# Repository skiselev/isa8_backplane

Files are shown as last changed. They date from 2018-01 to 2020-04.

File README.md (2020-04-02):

# ISA 8-bit Backplane
Compact ISA 8-bit Backplane board

## Introduction
This backplane was designed as a smaller version of [Micro ATX ISA Backplane](https://www.retrobrewcomputers.org/doku.php?id=boards:isa:isa-backplane:start). It can be used to build a compact IBM PC/XT compatible system using the [Micro 8088](https://github.com/skiselev/micro_8088)
processor board, and the 8-bit ISA cards that I've designed:
[ISA Super VGA](http://www.malinov.com/Home/sergeys-projects/isa-supervga),
[ISA Floppy Disk and Serial Controller](http://www.malinov.com/Home/sergeys-projects/isa-fdc-and-uart),
[XT-CF-Lite](http://www.malinov.com/Home/sergeys-projects/xt-cf-lite),
[ISA OPL2](http://www.malinov.com/Home/sergeys-projects/isa-opl2-card).

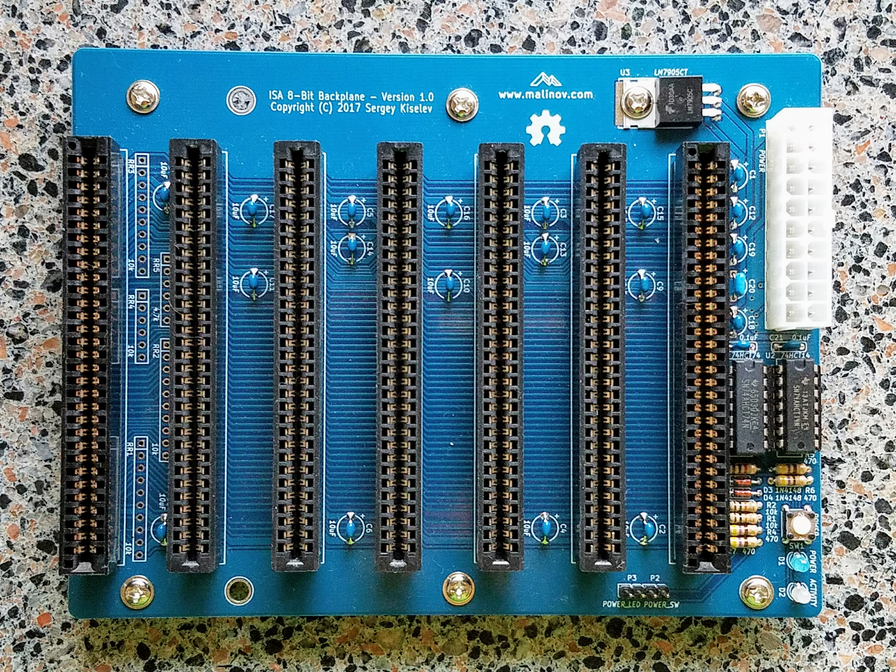
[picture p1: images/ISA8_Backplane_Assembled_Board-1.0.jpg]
ISA 8-bit Backplane V1.0 Assembled Board


## Specifications
* 7 ISA 8-bit (62 pin) slots
* ATX power supply connector, and ATX power control circuit
* Bi-color activity LED, that changes the color when the processor is executing the code (the color changes every time A7 address line changes its value)
* The form factor is (mostly) compatible with ATX / Micro ATX
* Pads for optional termination resistors

## Hardware Documentation

### Schematic and PCB Layout

[Schematic - Version 1.0](KiCad/ISA8_Backplane-Schematic-1.0.pdf)

[PCB Layout - Version 1.0](KiCad/ISA8_Backplane-Board-1.0.pdf)

### Building Insturctions

Please refer to [Building Instructions](Building_Instructions.md) page for detailed instructions.

### Jumpers, Connectors, and Switches

#### P1 - ATX power connector
Pin | Description                    | Pin | Description
--- | ------------------------------ | --- | ------------------------------
1   | +3.3V power supply (not used)  | 11  | +3.3V power supply (not used)
2   |	+3.3V power supply (not used)  | 12  | -12V power supply
3   |	GND                            | 13  | Ground
4   |	+5V power supply               | 14  | Power supply ON signal
5   |	Ground                         | 15  | Ground
6   |	+5V power supply               | 16  | Ground
7   | Ground                         | 17  | Ground
8   | Power good (not used)          | 18  | -5V power supply (not used)*
9   | +5V standby power supply       | 19  | +5V power supply
10  | +12V power supply              | 20  | +5V power supply

*Note: -5V is not provided by most ATX power supplies. It is generated using an on board voltage regulator instead*

#### P2 - Power Switch connector
Pin | Description
--- | -----------
1   | Ground
2   |	Power ON signal

#### P3 - Power LED connector
Pin | Description
--- | -----------
1   | LED+
2   |	Ground

#### SW1 - Power Switch
Press SW1 to turn power on or off. The SW1 is connected in parallel with P2

### Bill of Materials - Version 1.0

[ISA 8-bit Backplane project on Mouser.com](https://www.mouser.com/ProjectManager/ProjectDetail.aspx?AccessID=9a09040b52) - View and order all components except of the PCB.

[ISA 8-bit Backplane project on OSH Park](https://oshpark.com/shared_projects/Y8dcyt5m) - View and order the PCB.

Component type     | Reference | Description                       | Quantity | Possible sources and notes 
------------------ | --------- | --------------------------------- | -------- | --------------------------
PCB                |           | ISA 8-bit Backplane PCB - Version 1.0  | 1   | Refer to the [RetroBrew Computers Board Inventory](https://retrobrewcomputers.org/doku.php?id=boardinventory#xi_8088_project_sergey_kiselev) page for ordering information, or order from a PCB manufacturer of your choice using provided Gerber or KiCad files
Integrated Circuit | U1        | 74HCT74, DIP-14 package           | 1        | Mouser [595-SN74AHCT74N](https://www.mouser.com/ProductDetail/595-SN74AHCT74N)
Integrated Circuit | U2        | 74HCT14, DIP-14 package           | 1        | Mouser [595-SN74AHCT14N](https://www.mouser.com/ProductDetail/595-SN74AHCT14N)
Integrated Circuit | U3        | LM7905C -5V voltage regulator     | 1        | Mouser [512-LM7905CT](https://www.mouser.com/ProductDetail/512-LM7905CT)
IC Socket          | U1, U2    | DIP-14, 300 mil socket            | 2        | Mouser [517-4814-3000-CP](https://www.mouser.com/ProductDetail/517-4814-3000-CP)
LED                | D1        | 3 mm, blue LED indicator          | 1        | Mouser [696-SSL-LX3054USBD](https://www.mouser.com/ProductDetail/696-SSL-LX3054USBD)
LED                | D2        | 3 mm, bi-color red/green LED indicator | 1   | Mouser [696-SSL-LX3054IGW](https://www.mouser.com/ProductDetail/696-SSL-LX3054IGW)
Diode              | D3, D4    | 1N4148                            | 2        | Mouser [512-1N4148](https://www.mouser.com/ProductDetail/512-1N4148)
Tactile Button     | SW1       | 6 mm tactile button, straight     | 1        | Mouser [653-B3F-1000](https://www.mouser.com/ProductDetail/653-B3F-1000)
Connector          | P1        | 20 pin ATX power connector        | 1        | Mouser [538-46015-2006](https://www.mouser.com/ProductDetail/538-46015-2006)
Connector          | P2, P3    | 4 pin header, 2.54 mm pitch       | 2        | Mouser [649-68002-104HLF](https://www.mouser.com/ProductDetail/649-68002-104HLF)
Connector          | BUS1-BUS7 | 62 pin card edge connector, 2.54 mm pitch | 7 | Mouser [571-6-5530843-5](https://www.mouser.com/ProductDetail/571-6-5530843-5)
Capacitor          | C1 - C19  | 10 uF, 16V, MLCC, 5 mm lead spacing    | 19       | Mouser [810-FG28X5R1E106MR06](https://www.mouser.com/ProductDetail/810-FG28X5R1E106MR06)
Capacitor          | C20       | 1 uF, MLCC, 5 mm lead spacing     | 1        | Mouser [810-FG28X5R1H105KRT0](https://www.mouser.com/ProductDetail/810-FG28X5R1H105KRT0)
Capacitor          | C21, C22  | 0.1 uF, MLCC, 5 mm lead spacing   | 2        | Mouser [594-K104K15X7RF53H5](https://www.mouser.com/ProductDetail/594-K104K15X7RF53H5)
Resistor           | R1, R2    | 10 kohm, through hole             | 2        | Mouser [291-10K-RC](https://www.mouser.com/ProductDetail/291-10K-RC)
Resistor           | R3        | 1 kohm, through hole              | 1        | Mouser [291-1K-RC](https://www.mouser.com/ProductDetail/291-1K-RC)
Resistor           | R4 - R7   | 470 ohm, through hole             | 4        | Mouser [291-470-RC](https://www.mouser.com/ProductDetail/291-470-RC)
Resistor Array     | RR1 - RR5 | do not populate                   |          | Optional, should not be populated

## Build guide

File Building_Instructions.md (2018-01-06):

# ISA 8-bit Backplane - Building Instructions

## Prerequisites

### Tools, Equipment, and Supplies

* Soldering iron with a fine tip. Temperature controlled soldering station is recommended
* Needle nose pliers for forming components' leads
* Small side cutters for cutting components' leads
* Desk lamp, magnifying glass
* Solder suitable for soldering electronics. For example: rosin core Sn63/Pb37, Sn60/Pb40, or a lead-free solder such as Sn96.5/Ag3.0/Cu0.5 (sometimes referred to as SAC305)
* Solder wick for removing excess of solder
* 99% Isopropyl Alcohol for removing the excess of flux after soldering
* Lint free wipes, used toothbrush, cotton swabs for cleaning the PCB before and after soldering

### Parts

#### Procuring Parts
The list of parts provided in the [Bill of Materials](README.md#bill-of-materials---version-10) section of the [README.md](README.md) file. It also provides the recommended sources for the parts.
Most of the parts are available from electronic components distributors such as [Mouser](https://www.mouser.com/ProjectManager/ProjectDetail.aspx?AccessID=9a09040b52) and [Digi-Key](https://www.digikey.com).
Many components are also available, frequently cheaper, from smaller stores, such as [Unicorn Electronics](http://www.unicornelectronics.com/), or on eBay.

The ISA 8-bit Backplane PCBs are provided by the members of [RetroBrew Computers group](https://retrobrewcomputers.org/doku.php?id=boardinventory#xi_8088_project_sergey_kiselev).
Alternatively they can be ordered from a PCB manufacturing service, such as [OSH Park](https://oshpark.com/shared_projects/Y8dcyt5m),
using [Gerber](gerber) or [KiCad](KiCad) files provided in this GitHub repository.

It is highly recommended to use high quality gold plated card edge connectors (ISA 62-pin connectors). Using lower quality, especially old stock, corroded connectors will result in unreliable system.

#### Parts Replacement

* The recommended logic family is the CMOS 74HCT-series
  * Possible replacements are Advanced CMOS 74AHCT, or CMOS 74ACT-series logic
  * While TTL ICs (74LS, 74ALS, 74F) should work, they will result in higher power consumption
* LEDs:
  * Power LED - D1: It is recommended to use a 3 mm blue LED. 5 mm LEDs, as well as other colors would work as well.
  * Activity LED - D2: It is recommended to use a 3 mm red/green bi-color LED. This LED must be a bi-color LED with two leads. Such LEDs integrate two LED crystals, connected back to back (anode of one to cathod of the other, and vice-versa).
* It is recommended to use ceramic multilayer capacitors with 5 mm lead pitch
  * It is possible to use 2.5 mm lead pitch or axial capacitors by forming their leads accordingly
  * Electrolytic or tantalum capacitors can be used for C1-C19 10 uF. Make sure to observe the polarity in this case

## Building the ISA 8-bit Backplane Board

### Build Sequence

1. Inspect the PCB for obvious defects, such as deep scratches or short-circuits between traces
2. Clean the PCB with an alcohol wipe
3. Solder the components, going for lower profile to higher profile
  * Form the leads and solder the D3 and D4 diodes. Pay attention to the diode's polarity (the black band on the diode should match the band on the silkscreen)
  * Solder the R1-R7 resistors
  * Solder the SW1 tactile button
  * Form the leads and solder the U3 power regulator. Make sure that the heatsink mount hole is right above the mount hole in the PCB
  * Solder the C1-C22 capacitors. Pay attention to the capacitors polarity if using polarized capacitors
  * Solder the DIP sockets - U1, U2. Pay close attention to the orientation of the sockets
  * Solder the LEDs D1 and D2. Pay attention to the LED polarity for D1
  * Solder the P2 - P3 header
  * Solder the P1 ATX power connector
  * Solder the BUS1 - BUS7 ISA card edge connectors
4. Carefully inspect all the solder joints. Re-solder if needed. Optionally use a multimeter to check the board for short-circuits, and for the power supply signals connectivity
5. Clean the board using cotton swaps, wipes, and the toothbrush soaked in alcohol
6. Carefully install ICs into the sockets. Use a hard non-static surface to bend the pins of ICs in DIP packages as needed. Double check the orientation of the ICs. Make sure that all ICs pins are inserted into the sockets, and not bent
7. Inspect the completed board once again
8. Install the Micro 8088 board and other ISA cards in the ISA backplane. Connect the power supply
9. Turn on the power, test the board, install your favorite software, and enjoy!

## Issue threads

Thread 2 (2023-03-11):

24pin ATX

lis-86, 2023-03-11:
Possible rewiring to 24 pin ATX power?

prabathbr, 2023-06-07:
> Possible rewiring to 24 pin ATX power?

you can simple remove additional 4 pins or use 24 pin -> 20 pin extension cable for couple of $ to keep it clean.

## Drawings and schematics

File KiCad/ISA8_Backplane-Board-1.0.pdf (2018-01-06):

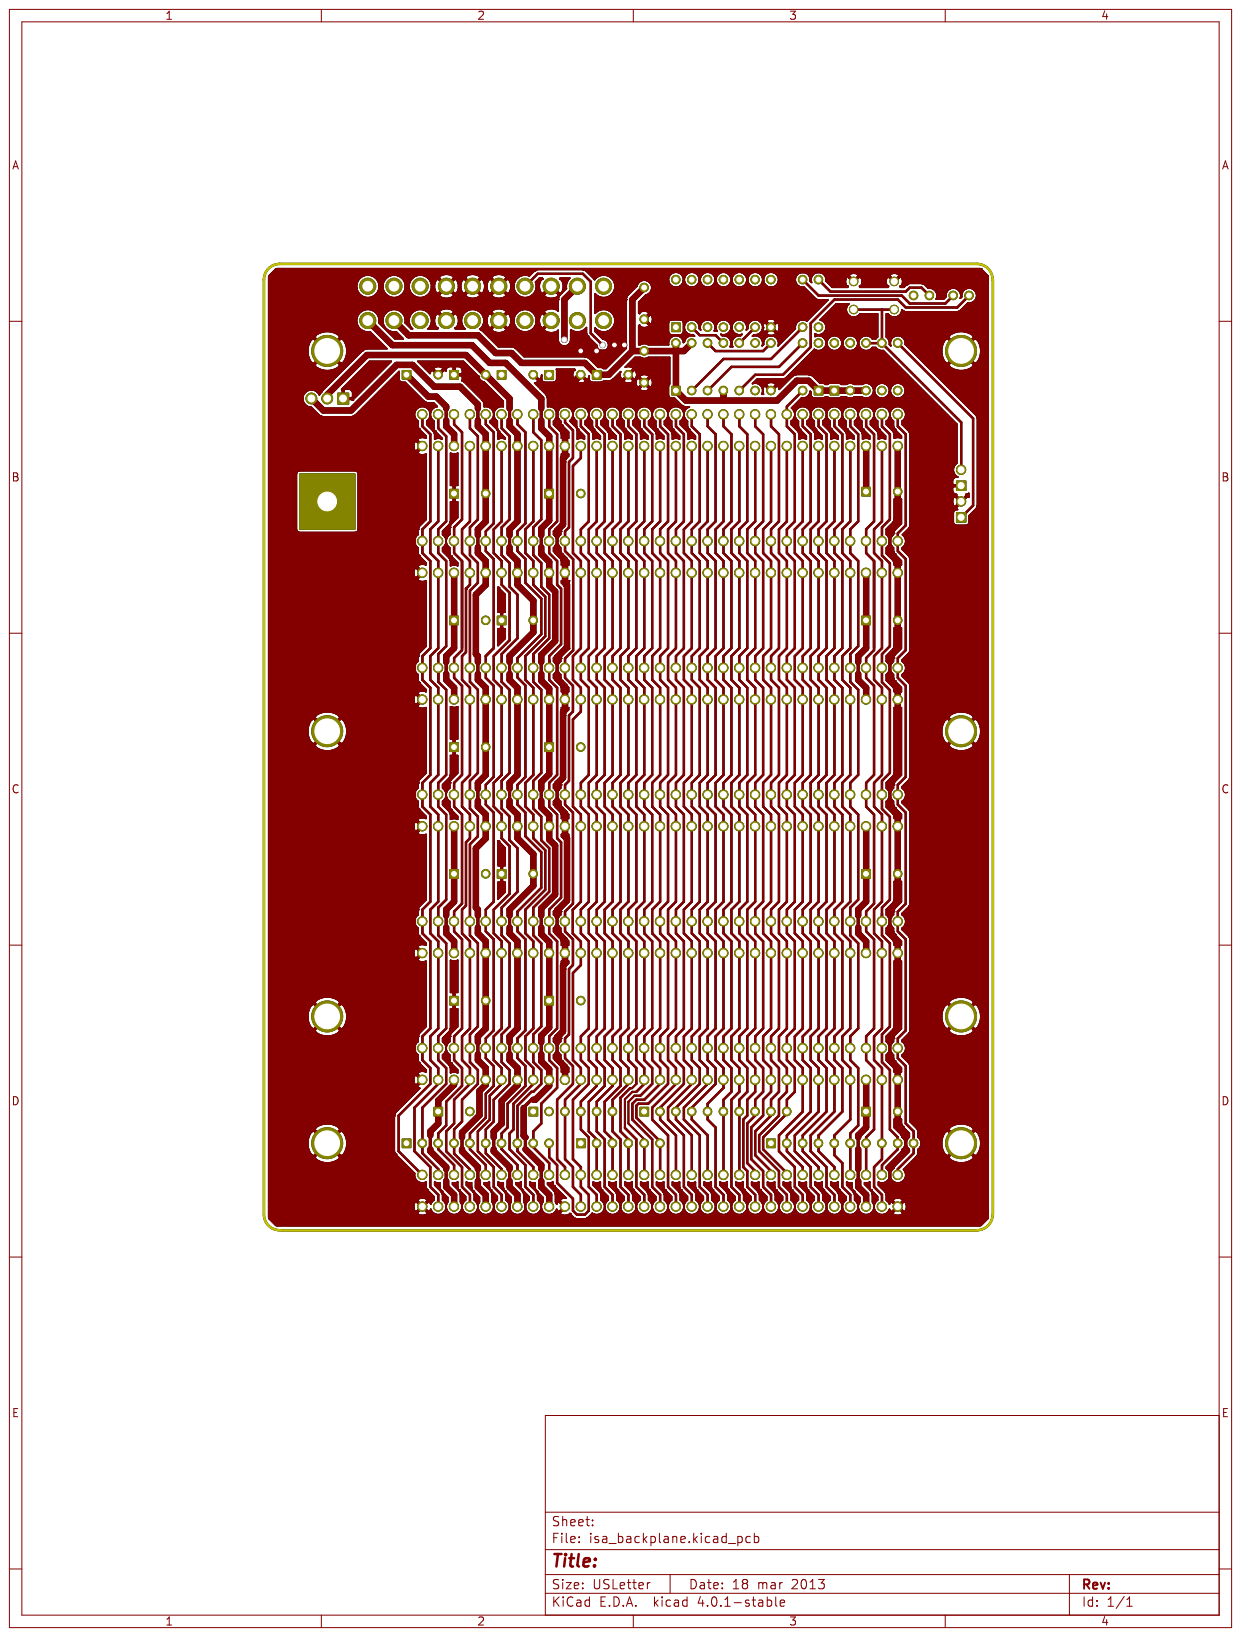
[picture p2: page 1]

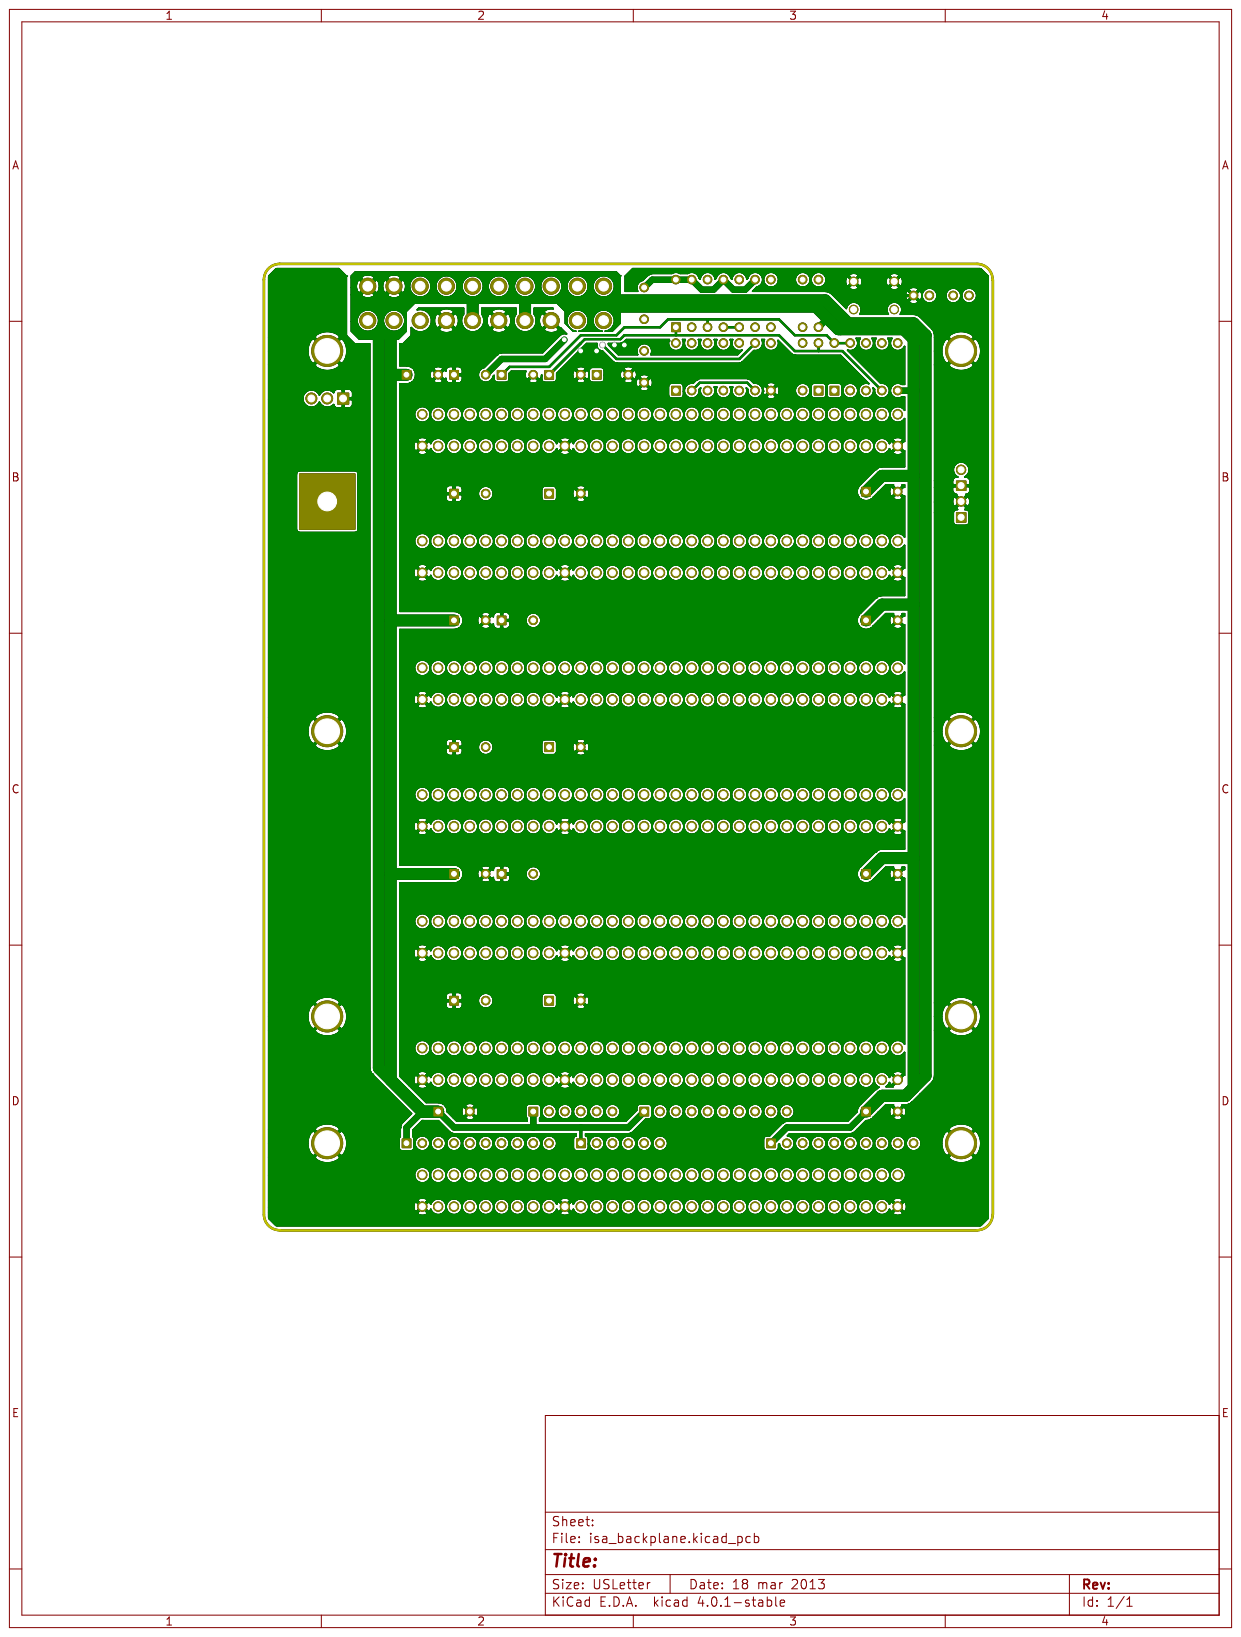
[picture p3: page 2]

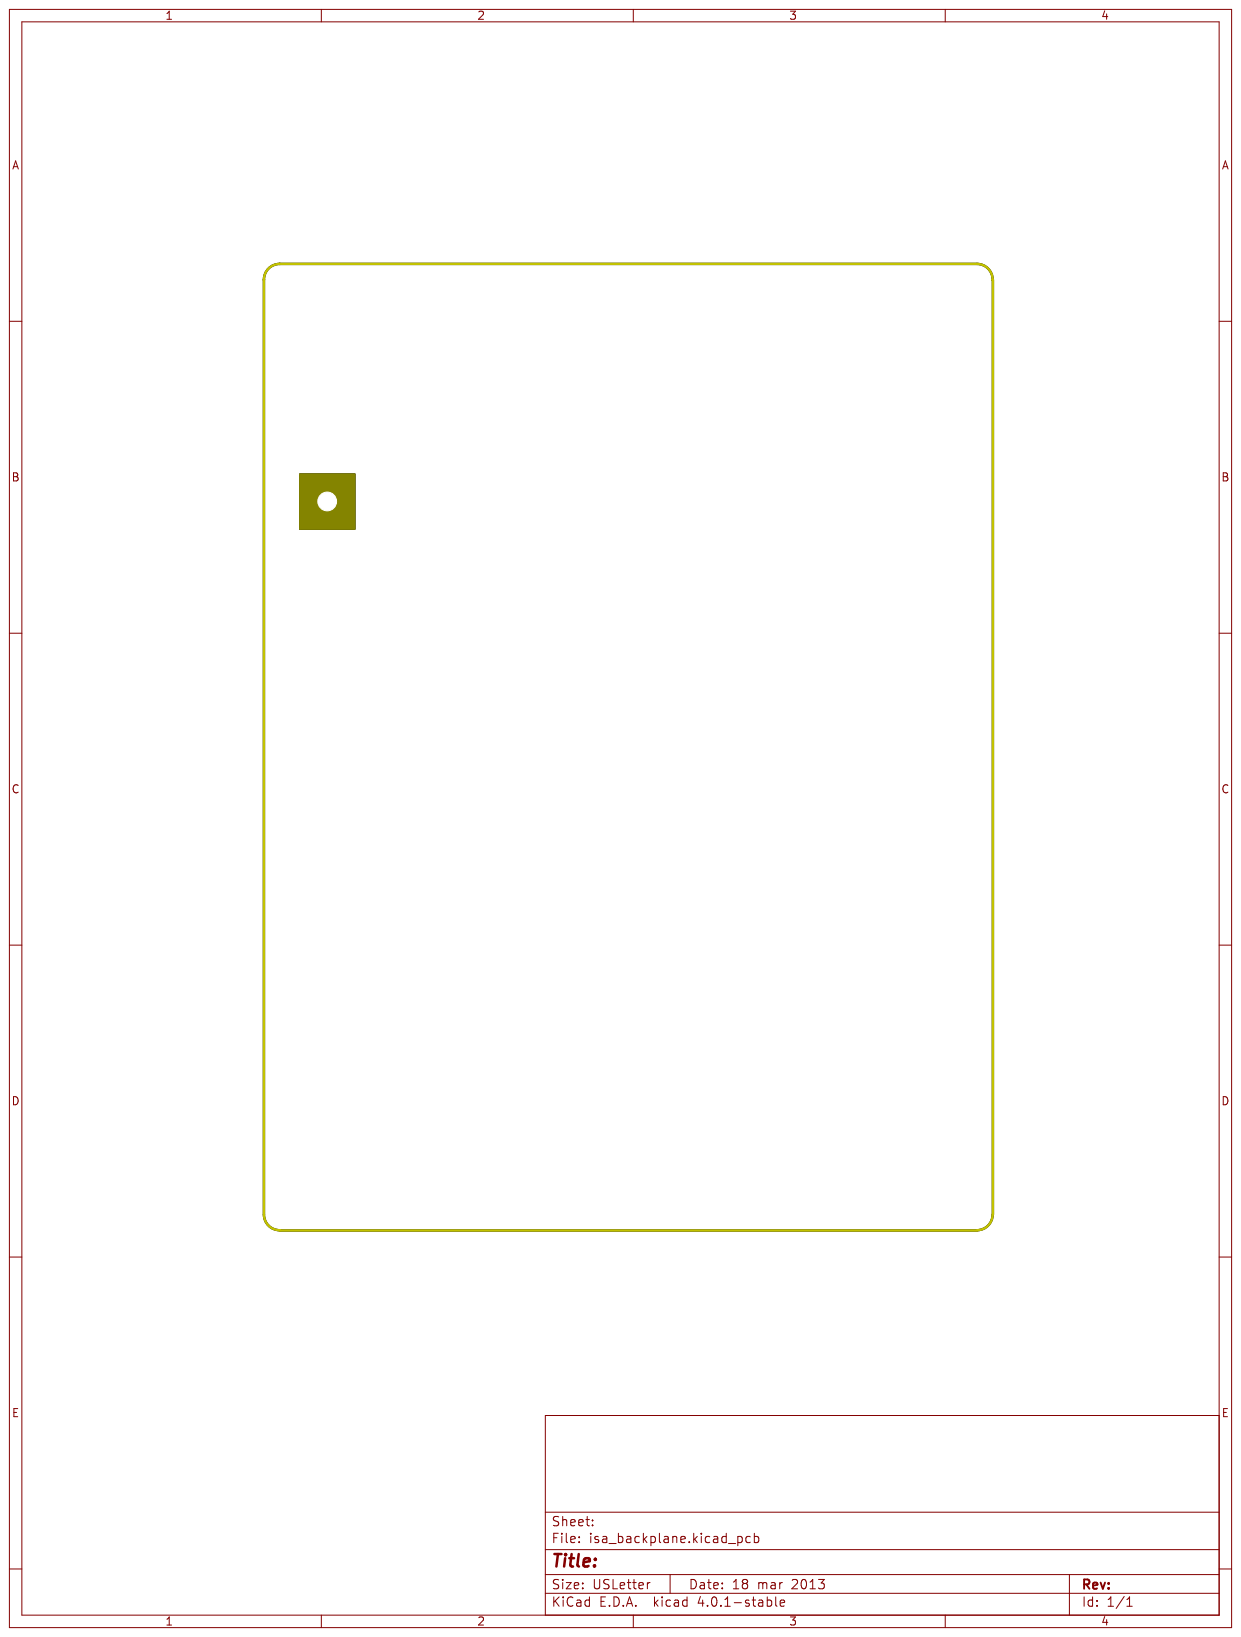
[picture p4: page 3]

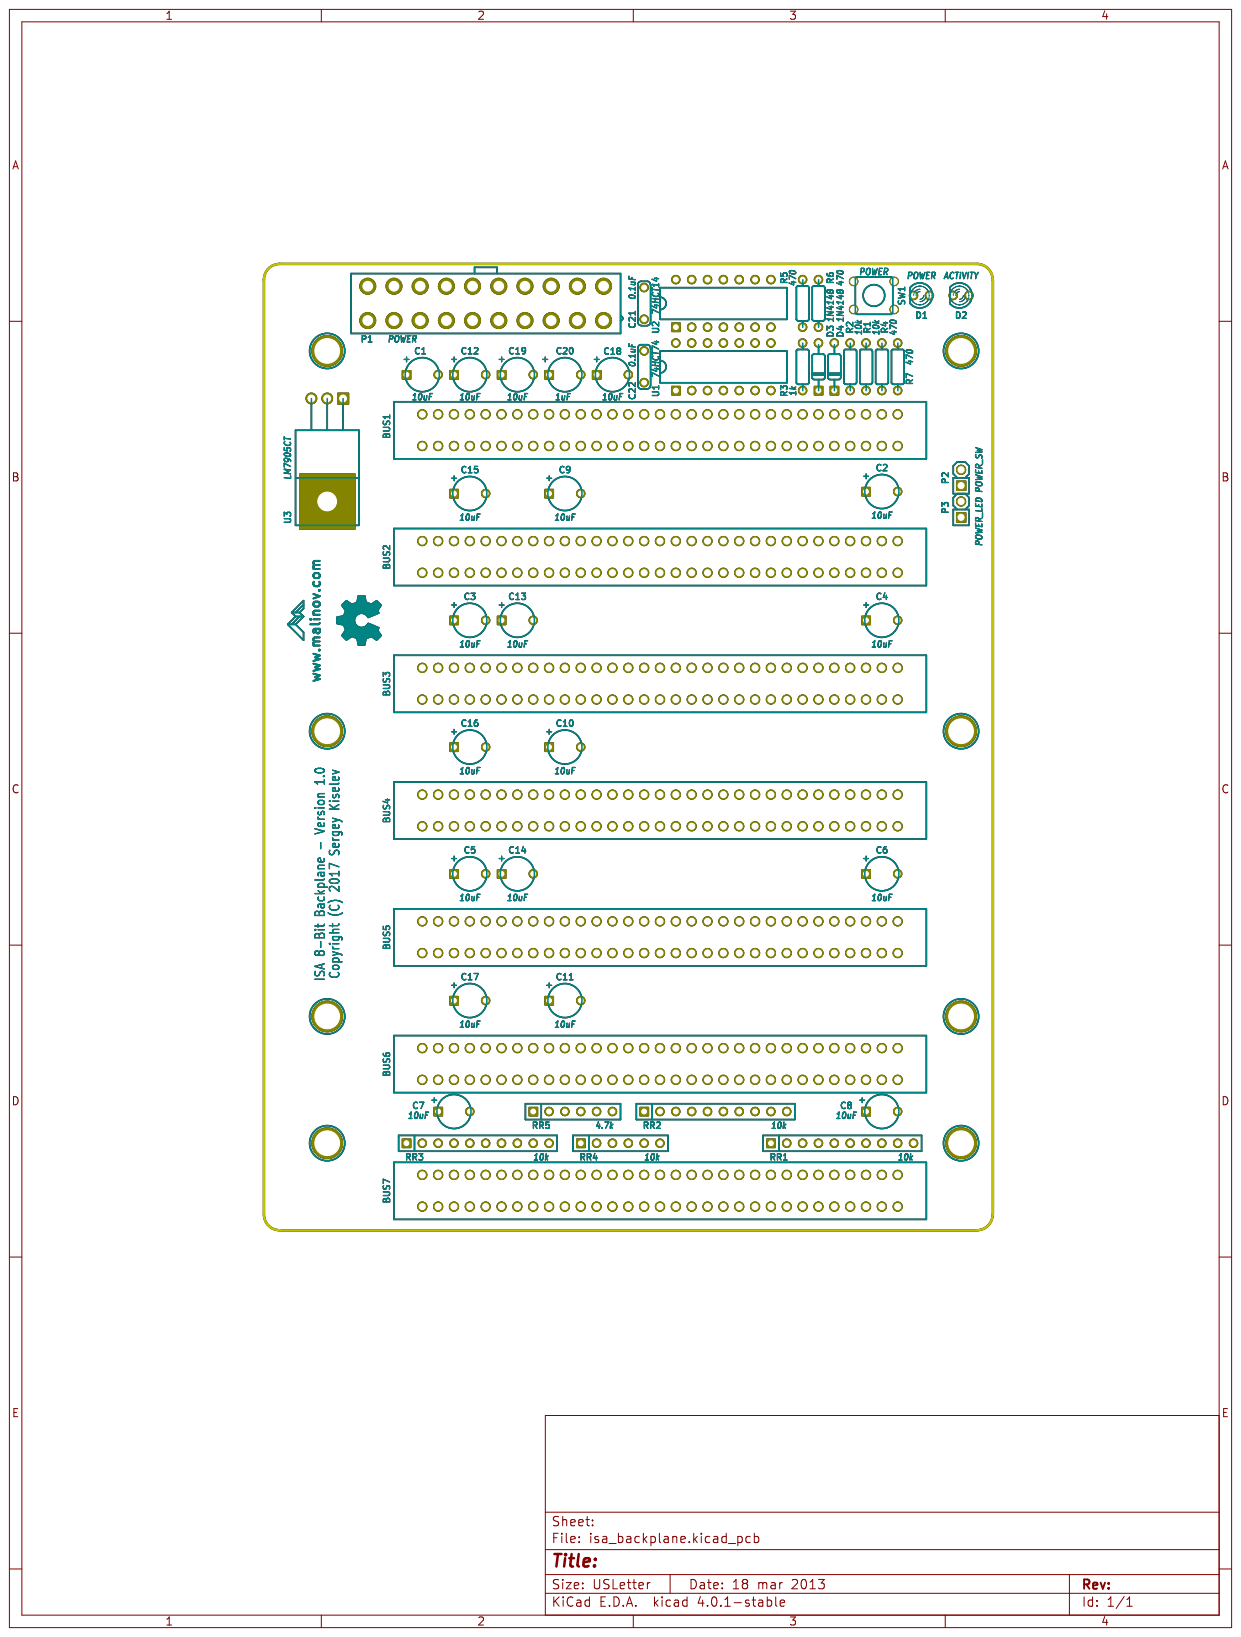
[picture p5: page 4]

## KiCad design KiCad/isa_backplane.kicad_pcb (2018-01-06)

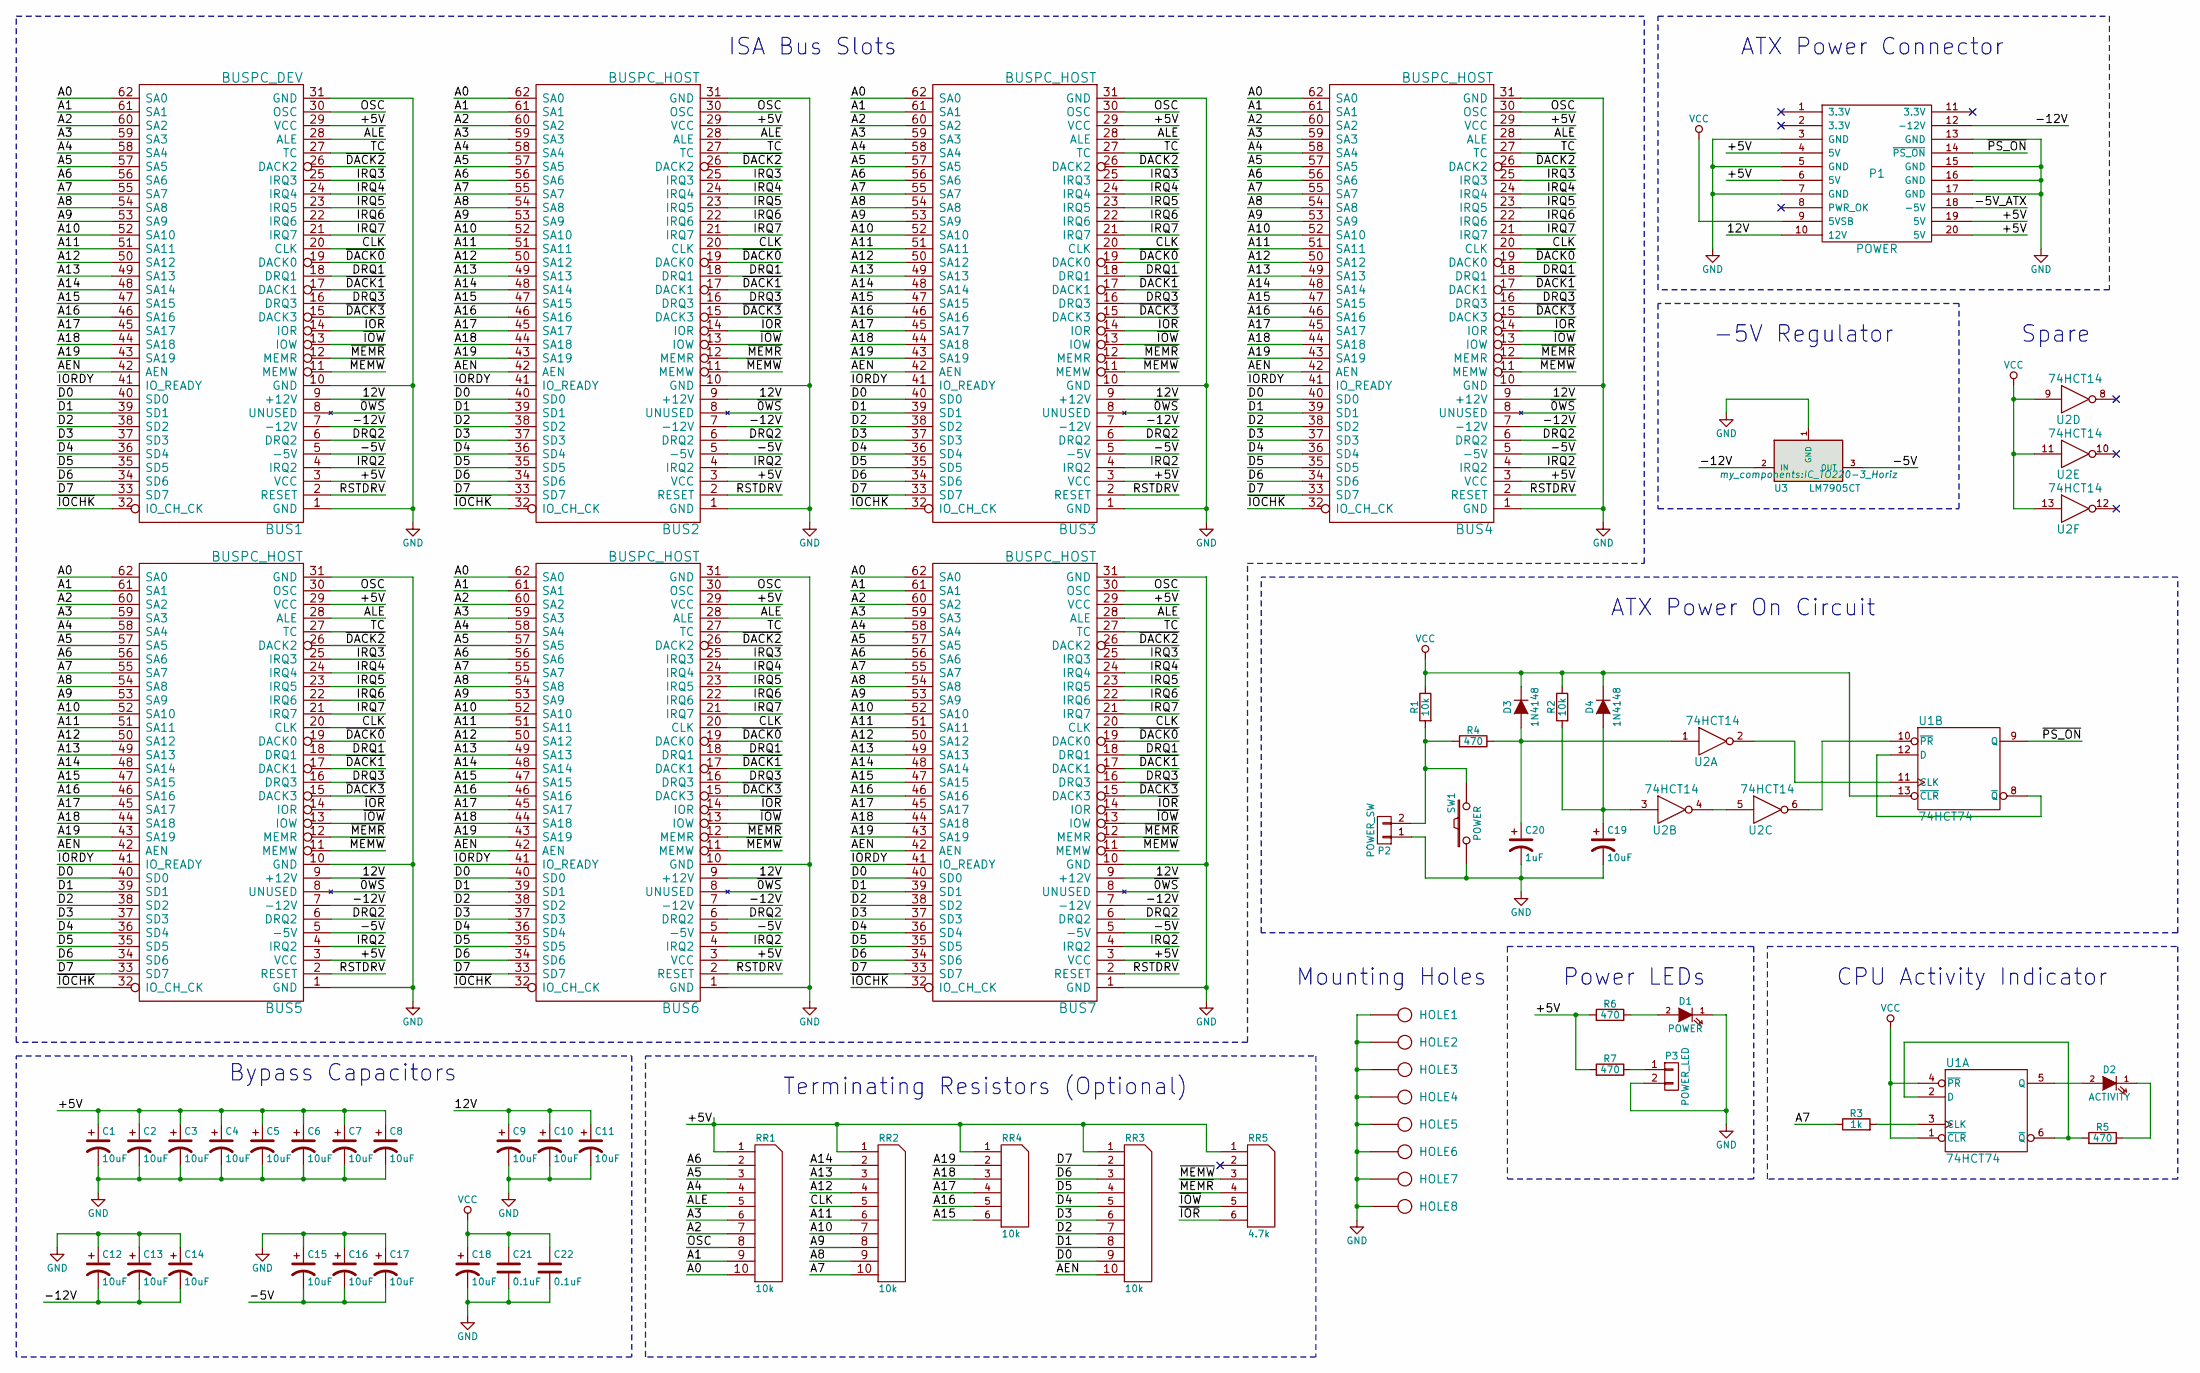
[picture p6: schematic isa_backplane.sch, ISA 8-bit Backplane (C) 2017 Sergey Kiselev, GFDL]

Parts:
BUS1: BUSPC_DEV; Conn_Edge_ISA8
BUS2, BUS3, BUS4, BUS5, BUS6, BUS7: BUSPC_HOST; Conn_Edge_ISA8
C1, C2, C3, C4, C5, C6, C7, C8, C9, C10, C11, C12, C13, C14, C15, C16, C17, C18, C19: 10uF; Cap_Tant_508
C20: 1uF; Cap_Tant_508
C21, C22: 0.1uF; Cap_Cer_508
D1: POWER; LED_3mm
D2: ACTIVITY; LED_3mm
D3, D4: 1N4148; Diode_762
HOLE1, HOLE2, HOLE3, HOLE4, HOLE5, HOLE6, HOLE7, HOLE8: HOLE; Hole_4mm
P1: POWER; Conn_Power_ATX_20pin
P2: POWER_SW; Conn_Pin_Header_2x1_2.54mm
P3: POWER_LED; Conn_Pin_Header_2x1_2.54mm
R1, R2: 10k; Res_762
R3: 1k; Res_762
R4, R5, R6, R7: 470; Res_762
RR1, RR2, RR3: 10k; Conn_SIL10
RR4: 10k; Conn_SIL6
RR5: 4.7k; Conn_SIL6
SW1: POWER; Switch_Tactile_6mm
U1: 74HCT74; IC_DIP14_300
U2: 74HCT14; IC_DIP14_300
U3: LM7905CT; IC_TO220-3_Horiz

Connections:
/12V: BUS1.9 (+12V), BUS2.9 (+12V), BUS3.9 (+12V), BUS4.9 (+12V), BUS5.9 (+12V), BUS6.9 (+12V), BUS7.9 (+12V), C9.1, C10.1, C11.1, P1.10 (12V)
/+5V: BUS1.3 (VCC), BUS1.29 (VCC), BUS2.3 (VCC), BUS2.29 (VCC), BUS3.3 (VCC), BUS3.29 (VCC), BUS4.3 (VCC), BUS4.29 (VCC), BUS5.3 (VCC), BUS5.29 (VCC), BUS6.3 (VCC), BUS6.29 (VCC), BUS7.3 (VCC), BUS7.29 (VCC), C1.1, C2.1, C3.1, C4.1, C5.1, C6.1, C7.1, C8.1, P1.4 (5V), P1.6 (5V), P1.19 (5V), P1.20 (5V), R6.2, R7.2, RR1.1 (COM), RR2.1 (COM), RR3.1 (COM), RR4.1 (COM), RR5.1 (COM)
/-5V: BUS1.5 (-5V), BUS2.5 (-5V), BUS3.5 (-5V), BUS4.5 (-5V), BUS5.5 (-5V), BUS6.5 (-5V), BUS7.5 (-5V), C15.2, C16.2, C17.2, U3.3 (OUT)
/-5V_ATX: P1.18 (-5V)
/-12V: BUS1.7 (-12V), BUS2.7 (-12V), BUS3.7 (-12V), BUS4.7 (-12V), BUS5.7 (-12V), BUS6.7 (-12V), BUS7.7 (-12V), C12.2, C13.2, C14.2, P1.12 (-12V), U3.2 (IN)
/A0: BUS1.62 (SA0), BUS2.62 (SA0), BUS3.62 (SA0), BUS4.62 (SA0), BUS5.62 (SA0), BUS6.62 (SA0), BUS7.62 (SA0), RR1.10
/A1: BUS1.61 (SA1), BUS2.61 (SA1), BUS3.61 (SA1), BUS4.61 (SA1), BUS5.61 (SA1), BUS6.61 (SA1), BUS7.61 (SA1), RR1.9
/A2: BUS1.60 (SA2), BUS2.60 (SA2), BUS3.60 (SA2), BUS4.60 (SA2), BUS5.60 (SA2), BUS6.60 (SA2), BUS7.60 (SA2), RR1.7
/A3: BUS1.59 (SA3), BUS2.59 (SA3), BUS3.59 (SA3), BUS4.59 (SA3), BUS5.59 (SA3), BUS6.59 (SA3), BUS7.59 (SA3), RR1.6
/A4: BUS1.58 (SA4), BUS2.58 (SA4), BUS3.58 (SA4), BUS4.58 (SA4), BUS5.58 (SA4), BUS6.58 (SA4), BUS7.58 (SA4), RR1.4
/A5: BUS1.57 (SA5), BUS2.57 (SA5), BUS3.57 (SA5), BUS4.57 (SA5), BUS5.57 (SA5), BUS6.57 (SA5), BUS7.57 (SA5), RR1.3
/A6: BUS1.56 (SA6), BUS2.56 (SA6), BUS3.56 (SA6), BUS4.56 (SA6), BUS5.56 (SA6), BUS6.56 (SA6), BUS7.56 (SA6), RR1.2
/A7: BUS1.55 (SA7), BUS2.55 (SA7), BUS3.55 (SA7), BUS4.55 (SA7), BUS5.55 (SA7), BUS6.55 (SA7), BUS7.55 (SA7), R3.1, RR2.10
/A8: BUS1.54 (SA8), BUS2.54 (SA8), BUS3.54 (SA8), BUS4.54 (SA8), BUS5.54 (SA8), BUS6.54 (SA8), BUS7.54 (SA8), RR2.9
/A9: BUS1.53 (SA9), BUS2.53 (SA9), BUS3.53 (SA9), BUS4.53 (SA9), BUS5.53 (SA9), BUS6.53 (SA9), BUS7.53 (SA9), RR2.8
/A10: BUS1.52 (SA10), BUS2.52 (SA10), BUS3.52 (SA10), BUS4.52 (SA10), BUS5.52 (SA10), BUS6.52 (SA10), BUS7.52 (SA10), RR2.7
/A11: BUS1.51 (SA11), BUS2.51 (SA11), BUS3.51 (SA11), BUS4.51 (SA11), BUS5.51 (SA11), BUS6.51 (SA11), BUS7.51 (SA11), RR2.6
/A12: BUS1.50 (SA12), BUS2.50 (SA12), BUS3.50 (SA12), BUS4.50 (SA12), BUS5.50 (SA12), BUS6.50 (SA12), BUS7.50 (SA12), RR2.4
/A13: BUS1.49 (SA13), BUS2.49 (SA13), BUS3.49 (SA13), BUS4.49 (SA13), BUS5.49 (SA13), BUS6.49 (SA13), BUS7.49 (SA13), RR2.3
/A14: BUS1.48 (SA14), BUS2.48 (SA14), BUS3.48 (SA14), BUS4.48 (SA14), BUS5.48 (SA14), BUS6.48 (SA14), BUS7.48 (SA14), RR2.2
/A15: BUS1.47 (SA15), BUS2.47 (SA15), BUS3.47 (SA15), BUS4.47 (SA15), BUS5.47 (SA15), BUS6.47 (SA15), BUS7.47 (SA15), RR4.6
/A16: BUS1.46 (SA16), BUS2.46 (SA16), BUS3.46 (SA16), BUS4.46 (SA16), BUS5.46 (SA16), BUS6.46 (SA16), BUS7.46 (SA16), RR4.5
/A17: BUS1.45 (SA17), BUS2.45 (SA17), BUS3.45 (SA17), BUS4.45 (SA17), BUS5.45 (SA17), BUS6.45 (SA17), BUS7.45 (SA17), RR4.4
/A18: BUS1.44 (SA18), BUS2.44 (SA18), BUS3.44 (SA18), BUS4.44 (SA18), BUS5.44 (SA18), BUS6.44 (SA18), BUS7.44 (SA18), RR4.3
/A19: BUS1.43 (SA19), BUS2.43 (SA19), BUS3.43 (SA19), BUS4.43 (SA19), BUS5.43 (SA19), BUS6.43 (SA19), BUS7.43 (SA19), RR4.2
/AEN: BUS1.42 (AEN), BUS2.42 (AEN), BUS3.42 (AEN), BUS4.42 (AEN), BUS5.42 (AEN), BUS6.42 (AEN), BUS7.42 (AEN), RR3.10
/ALE: BUS1.28 (ALE), BUS2.28 (ALE), BUS3.28 (ALE), BUS4.28 (ALE), BUS5.28 (ALE), BUS6.28 (ALE), BUS7.28 (ALE), RR1.5
/CLK: BUS1.20 (CLK), BUS2.20 (CLK), BUS3.20 (CLK), BUS4.20 (CLK), BUS5.20 (CLK), BUS6.20 (CLK), BUS7.20 (CLK), RR2.5
/D0: BUS1.40 (SD0), BUS2.40 (SD0), BUS3.40 (SD0), BUS4.40 (SD0), BUS5.40 (SD0), BUS6.40 (SD0), BUS7.40 (SD0), RR3.9
/D1: BUS1.39 (SD1), BUS2.39 (SD1), BUS3.39 (SD1), BUS4.39 (SD1), BUS5.39 (SD1), BUS6.39 (SD1), BUS7.39 (SD1), RR3.8
/D2: BUS1.38 (SD2), BUS2.38 (SD2), BUS3.38 (SD2), BUS4.38 (SD2), BUS5.38 (SD2), BUS6.38 (SD2), BUS7.38 (SD2), RR3.7
/D3: BUS1.37 (SD3), BUS2.37 (SD3), BUS3.37 (SD3), BUS4.37 (SD3), BUS5.37 (SD3), BUS6.37 (SD3), BUS7.37 (SD3), RR3.6
/D4: BUS1.36 (SD4), BUS2.36 (SD4), BUS3.36 (SD4), BUS4.36 (SD4), BUS5.36 (SD4), BUS6.36 (SD4), BUS7.36 (SD4), RR3.5
/D5: BUS1.35 (SD5), BUS2.35 (SD5), BUS3.35 (SD5), BUS4.35 (SD5), BUS5.35 (SD5), BUS6.35 (SD5), BUS7.35 (SD5), RR3.4
/D6: BUS1.34 (SD6), BUS2.34 (SD6), BUS3.34 (SD6), BUS4.34 (SD6), BUS5.34 (SD6), BUS6.34 (SD6), BUS7.34 (SD6), RR3.3
/D7: BUS1.33 (SD7), BUS2.33 (SD7), BUS3.33 (SD7), BUS4.33 (SD7), BUS5.33 (SD7), BUS6.33 (SD7), BUS7.33 (SD7), RR3.2
/DRQ1: BUS1.18 (DRQ1), BUS2.18 (DRQ1), BUS3.18 (DRQ1), BUS4.18 (DRQ1), BUS5.18 (DRQ1), BUS6.18 (DRQ1), BUS7.18 (DRQ1)
/DRQ2: BUS1.6 (DRQ2), BUS2.6 (DRQ2), BUS3.6 (DRQ2), BUS4.6 (DRQ2), BUS5.6 (DRQ2), BUS6.6 (DRQ2), BUS7.6 (DRQ2)
/DRQ3: BUS1.16 (DRQ3), BUS2.16 (DRQ3), BUS3.16 (DRQ3), BUS4.16 (DRQ3), BUS5.16 (DRQ3), BUS6.16 (DRQ3), BUS7.16 (DRQ3)
/IORDY: BUS1.41 (IO_READY), BUS2.41 (IO_READY), BUS3.41 (IO_READY), BUS4.41 (IO_READY), BUS5.41 (IO_READY), BUS6.41 (IO_READY), BUS7.41 (IO_READY)
/IRQ2: BUS1.4 (IRQ2), BUS2.4 (IRQ2), BUS3.4 (IRQ2), BUS4.4 (IRQ2), BUS5.4 (IRQ2), BUS6.4 (IRQ2), BUS7.4 (IRQ2)
/IRQ3: BUS1.25 (IRQ3), BUS2.25 (IRQ3), BUS3.25 (IRQ3), BUS4.25 (IRQ3), BUS5.25 (IRQ3), BUS6.25 (IRQ3), BUS7.25 (IRQ3)
/IRQ4: BUS1.24 (IRQ4), BUS2.24 (IRQ4), BUS3.24 (IRQ4), BUS4.24 (IRQ4), BUS5.24 (IRQ4), BUS6.24 (IRQ4), BUS7.24 (IRQ4)
/IRQ5: BUS1.23 (IRQ5), BUS2.23 (IRQ5), BUS3.23 (IRQ5), BUS4.23 (IRQ5), BUS5.23 (IRQ5), BUS6.23 (IRQ5), BUS7.23 (IRQ5)
/IRQ6: BUS1.22 (IRQ6), BUS2.22 (IRQ6), BUS3.22 (IRQ6), BUS4.22 (IRQ6), BUS5.22 (IRQ6), BUS6.22 (IRQ6), BUS7.22 (IRQ6)
/IRQ7: BUS1.21 (IRQ7), BUS2.21 (IRQ7), BUS3.21 (IRQ7), BUS4.21 (IRQ7), BUS5.21 (IRQ7), BUS6.21 (IRQ7), BUS7.21 (IRQ7)
/OSC: BUS1.30 (OSC), BUS2.30 (OSC), BUS3.30 (OSC), BUS4.30 (OSC), BUS5.30 (OSC), BUS6.30 (OSC), BUS7.30 (OSC), RR1.8
/RSTDRV: BUS1.2 (RESET), BUS2.2 (RESET), BUS3.2 (RESET), BUS4.2 (RESET), BUS5.2 (RESET), BUS6.2 (RESET), BUS7.2 (RESET)
/TC: BUS1.27 (TC), BUS2.27 (TC), BUS3.27 (TC), BUS4.27 (TC), BUS5.27 (TC), BUS6.27 (TC), BUS7.27 (TC)
/~0WS: BUS1.8 (UNUSED), BUS2.8 (UNUSED), BUS3.8 (UNUSED), BUS4.8 (UNUSED), BUS5.8 (UNUSED), BUS6.8 (UNUSED), BUS7.8 (UNUSED)
/~DACK0: BUS1.19 (DACK0), BUS2.19 (DACK0), BUS3.19 (DACK0), BUS4.19 (DACK0), BUS5.19 (DACK0), BUS6.19 (DACK0), BUS7.19 (DACK0)
/~DACK1: BUS1.17 (DACK1), BUS2.17 (DACK1), BUS3.17 (DACK1), BUS4.17 (DACK1), BUS5.17 (DACK1), BUS6.17 (DACK1), BUS7.17 (DACK1)
/~DACK2: BUS1.26 (DACK2), BUS2.26 (DACK2), BUS3.26 (DACK2), BUS4.26 (DACK2), BUS5.26 (DACK2), BUS6.26 (DACK2), BUS7.26 (DACK2)
/~DACK3: BUS1.15 (DACK3), BUS2.15 (DACK3), BUS3.15 (DACK3), BUS4.15 (DACK3), BUS5.15 (DACK3), BUS6.15 (DACK3), BUS7.15 (DACK3)
/~IOCHK: BUS1.32 (IO_CH_CK), BUS2.32 (IO_CH_CK), BUS3.32 (IO_CH_CK), BUS4.32 (IO_CH_CK), BUS5.32 (IO_CH_CK), BUS6.32 (IO_CH_CK), BUS7.32 (IO_CH_CK)
/~IOR: BUS1.14 (IOR), BUS2.14 (IOR), BUS3.14 (IOR), BUS4.14 (IOR), BUS5.14 (IOR), BUS6.14 (IOR), BUS7.14 (IOR), RR5.6
/~IOW: BUS1.13 (IOW), BUS2.13 (IOW), BUS3.13 (IOW), BUS4.13 (IOW), BUS5.13 (IOW), BUS6.13 (IOW), BUS7.13 (IOW), RR5.5
/~MEMR: BUS1.12 (MEMR), BUS2.12 (MEMR), BUS3.12 (MEMR), BUS4.12 (MEMR), BUS5.12 (MEMR), BUS6.12 (MEMR), BUS7.12 (MEMR), RR5.4
/~MEMW: BUS1.11 (MEMW), BUS2.11 (MEMW), BUS3.11 (MEMW), BUS4.11 (MEMW), BUS5.11 (MEMW), BUS6.11 (MEMW), BUS7.11 (MEMW), RR5.3
/~PS_ON: P1.14 (~PS_ON), U1.9 (Q)
GND: BUS1.1 (GND), BUS1.10 (GND), BUS1.31 (GND), BUS2.1 (GND), BUS2.10 (GND), BUS2.31 (GND), BUS3.1 (GND), BUS3.10 (GND), BUS3.31 (GND), BUS4.1 (GND), BUS4.10 (GND), BUS4.31 (GND), BUS5.1 (GND), BUS5.10 (GND), BUS5.31 (GND), BUS6.1 (GND), BUS6.10 (GND), BUS6.31 (GND), BUS7.1 (GND), BUS7.10 (GND), BUS7.31 (GND), C1.2, C2.2, C3.2, C4.2, C5.2, C6.2, C7.2, C8.2, C9.2, C10.2, C11.2, C12.1, C13.1, C14.1, C15.1, C16.1, C17.1, C18.2, C19.2, C20.2, C21.2, C22.2, D1.1 (K), HOLE1.1, HOLE2.1, HOLE3.1, HOLE4.1, HOLE5.1, HOLE6.1, HOLE7.1, HOLE8.1, P1.3 (GND), P1.5 (GND), P1.7 (GND), P1.13 (GND), P1.15 (GND), P1.16 (GND), P1.17 (GND), P2.1, P3.2, SW1.1, U1.7 (GND), U2.7 (GND), U3.1 (GND)
unnamed: C19.1, D4.2 (A), R2.2, U2.3
unnamed: C20.1, D3.2 (A), R4.1, U2.1
unnamed: D1.2 (A), R6.1
unnamed: D2.1 (K), R5.1
unnamed: D2.2 (A), U1.5 (Q)
unnamed: P2.2, R1.2, R4.2, SW1.2
unnamed: P3.1, R7.1
unnamed: R3.2, U1.3 (CLK)
unnamed: R5.2, U1.2 (D), U1.6 (~Q)
unnamed: U1.10 (~PR), U2.6
unnamed: U1.11 (CLK), U2.2
unnamed: U1.8 (~Q), U1.12 (D)
unnamed: U2.4, U2.5
VCC: C18.1, C21.1, C22.1, D3.1 (K), D4.1 (K), P1.9 (5VSB), R1.1, R2.1, U1.1 (~CLR), U1.4 (~PR), U1.13 (~CLR), U1.14 (VCC), U2.9, U2.11, U2.13, U2.14 (VCC)

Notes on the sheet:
Power LEDs
-5V Regulator
CPU Activity Indicator
ATX Power Connector
Mounting Holes
ATX Power On Circuit
Bypass Capacitors
ISA Bus Slots
Terminating Resistors (Optional)
Spare

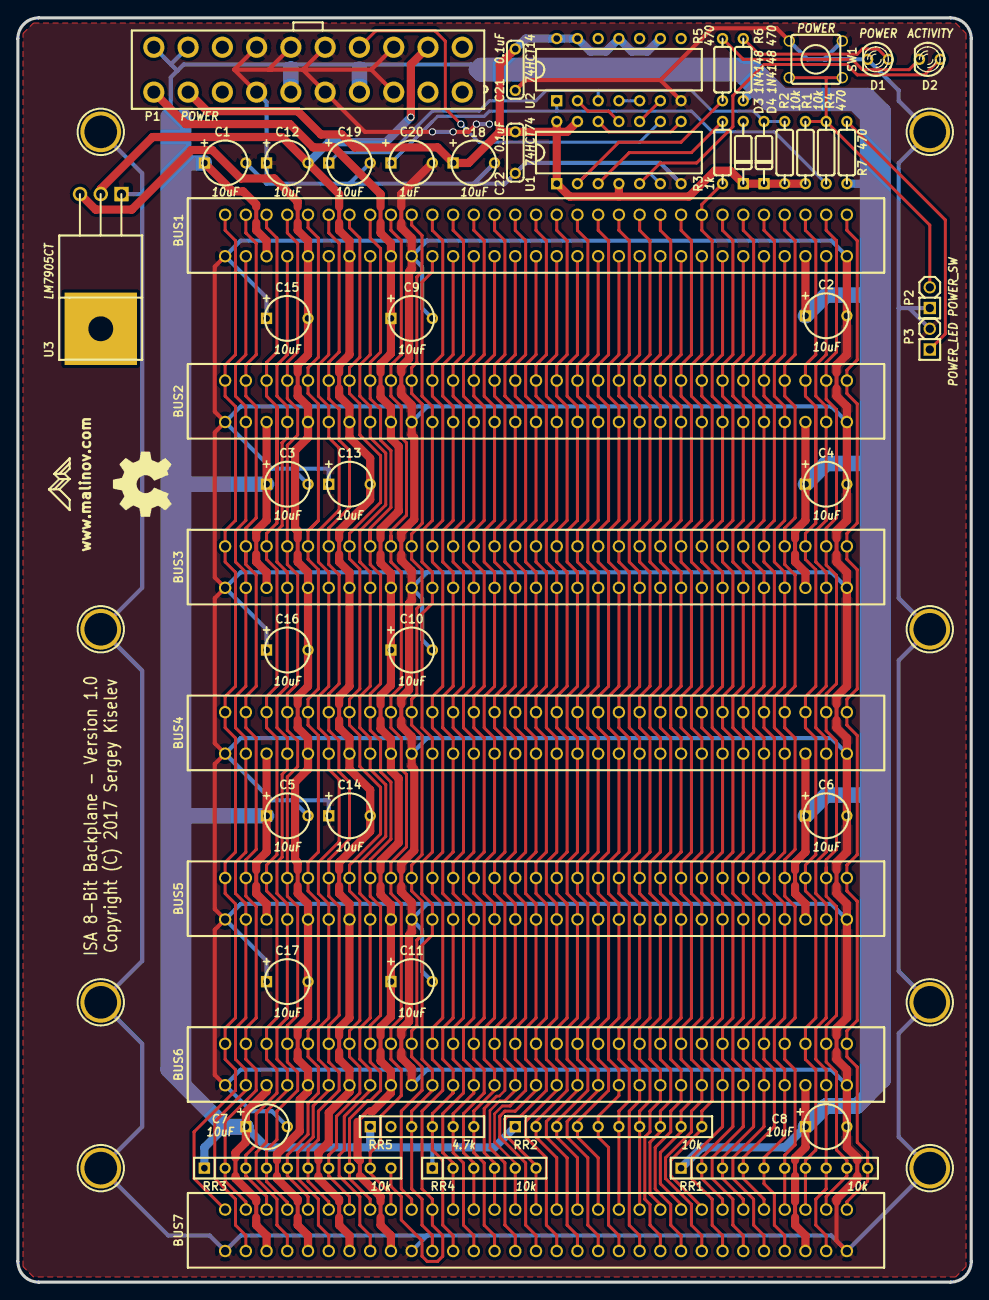
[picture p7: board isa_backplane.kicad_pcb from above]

Board: 2 copper layers, 116.8 x 154.9 mm, 60 parts (0 on the bottom side), 74 nets.

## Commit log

2018-01-06 add the files
    [isa_backplane-B.Mask.gbs, isa_backplane-B.SilkS.gbo, isa_backplane-Back.gbl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]
2018-01-06 add board picture
2018-01-06 README.md: Add board photo
2018-01-06 README.md: Update BOM
2018-01-09 README.md: Update C1-C19 type - needs to be >= 16V
2020-04-02 README: Update the quantity of 470 ohm resistors

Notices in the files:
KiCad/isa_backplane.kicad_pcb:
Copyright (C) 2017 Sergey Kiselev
